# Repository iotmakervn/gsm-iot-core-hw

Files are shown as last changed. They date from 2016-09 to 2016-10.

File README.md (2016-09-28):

# Dự án GSM-IOT-CORE

## Mô tả tính năng

## Phần cứng

### Mạch nguyên lý

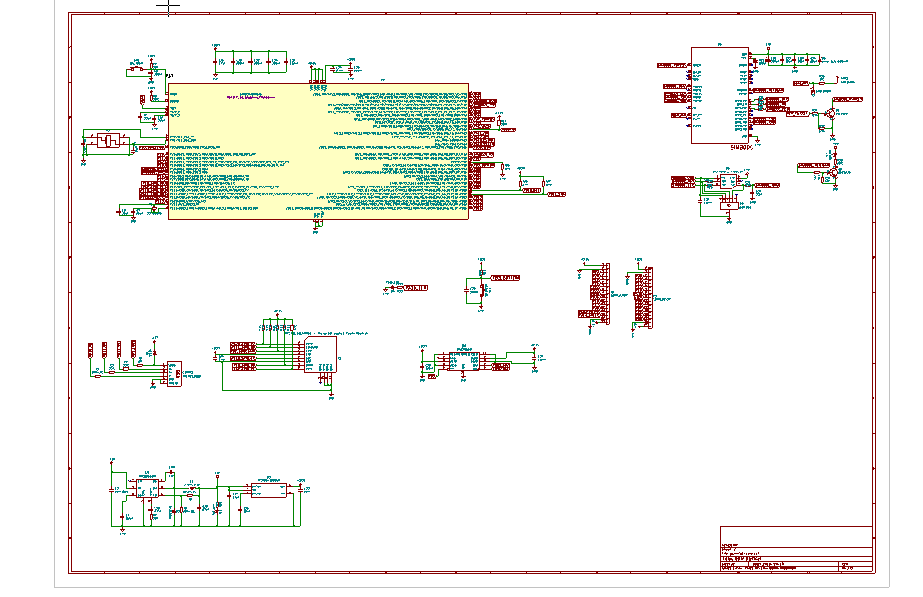
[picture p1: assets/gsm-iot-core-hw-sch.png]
GSM IOT CORE HW Schematic


### Mạch PCB

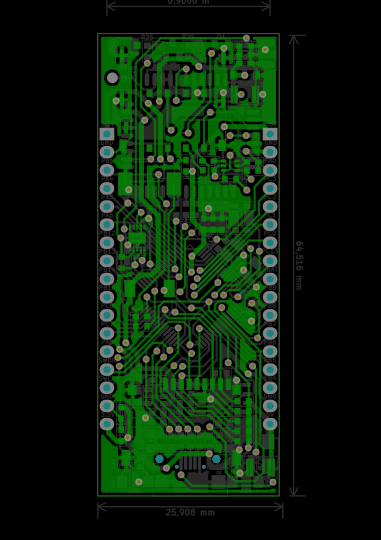
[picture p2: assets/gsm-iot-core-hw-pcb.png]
GSM IOT CORE HW PCB


### 3D
#### Top view
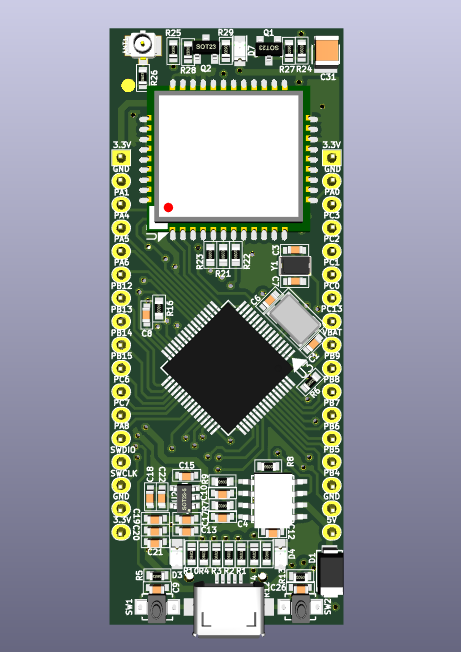
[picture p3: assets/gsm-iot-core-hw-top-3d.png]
GSM IOT CORE HW 3D TOP PCB


#### Button view
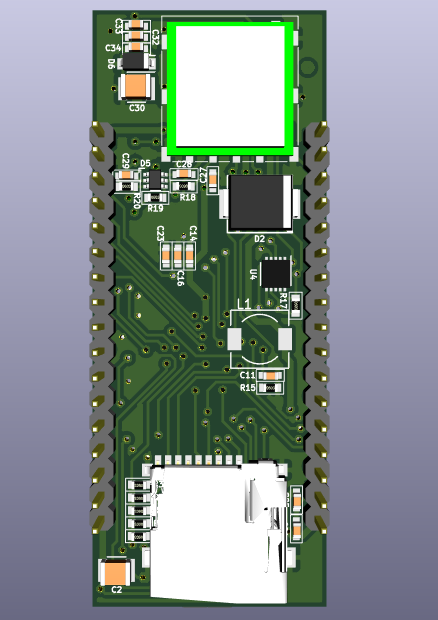
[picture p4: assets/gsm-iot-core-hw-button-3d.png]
GSM IOT CORE HW 3D TOP PCB


### Film

# Giấy phép

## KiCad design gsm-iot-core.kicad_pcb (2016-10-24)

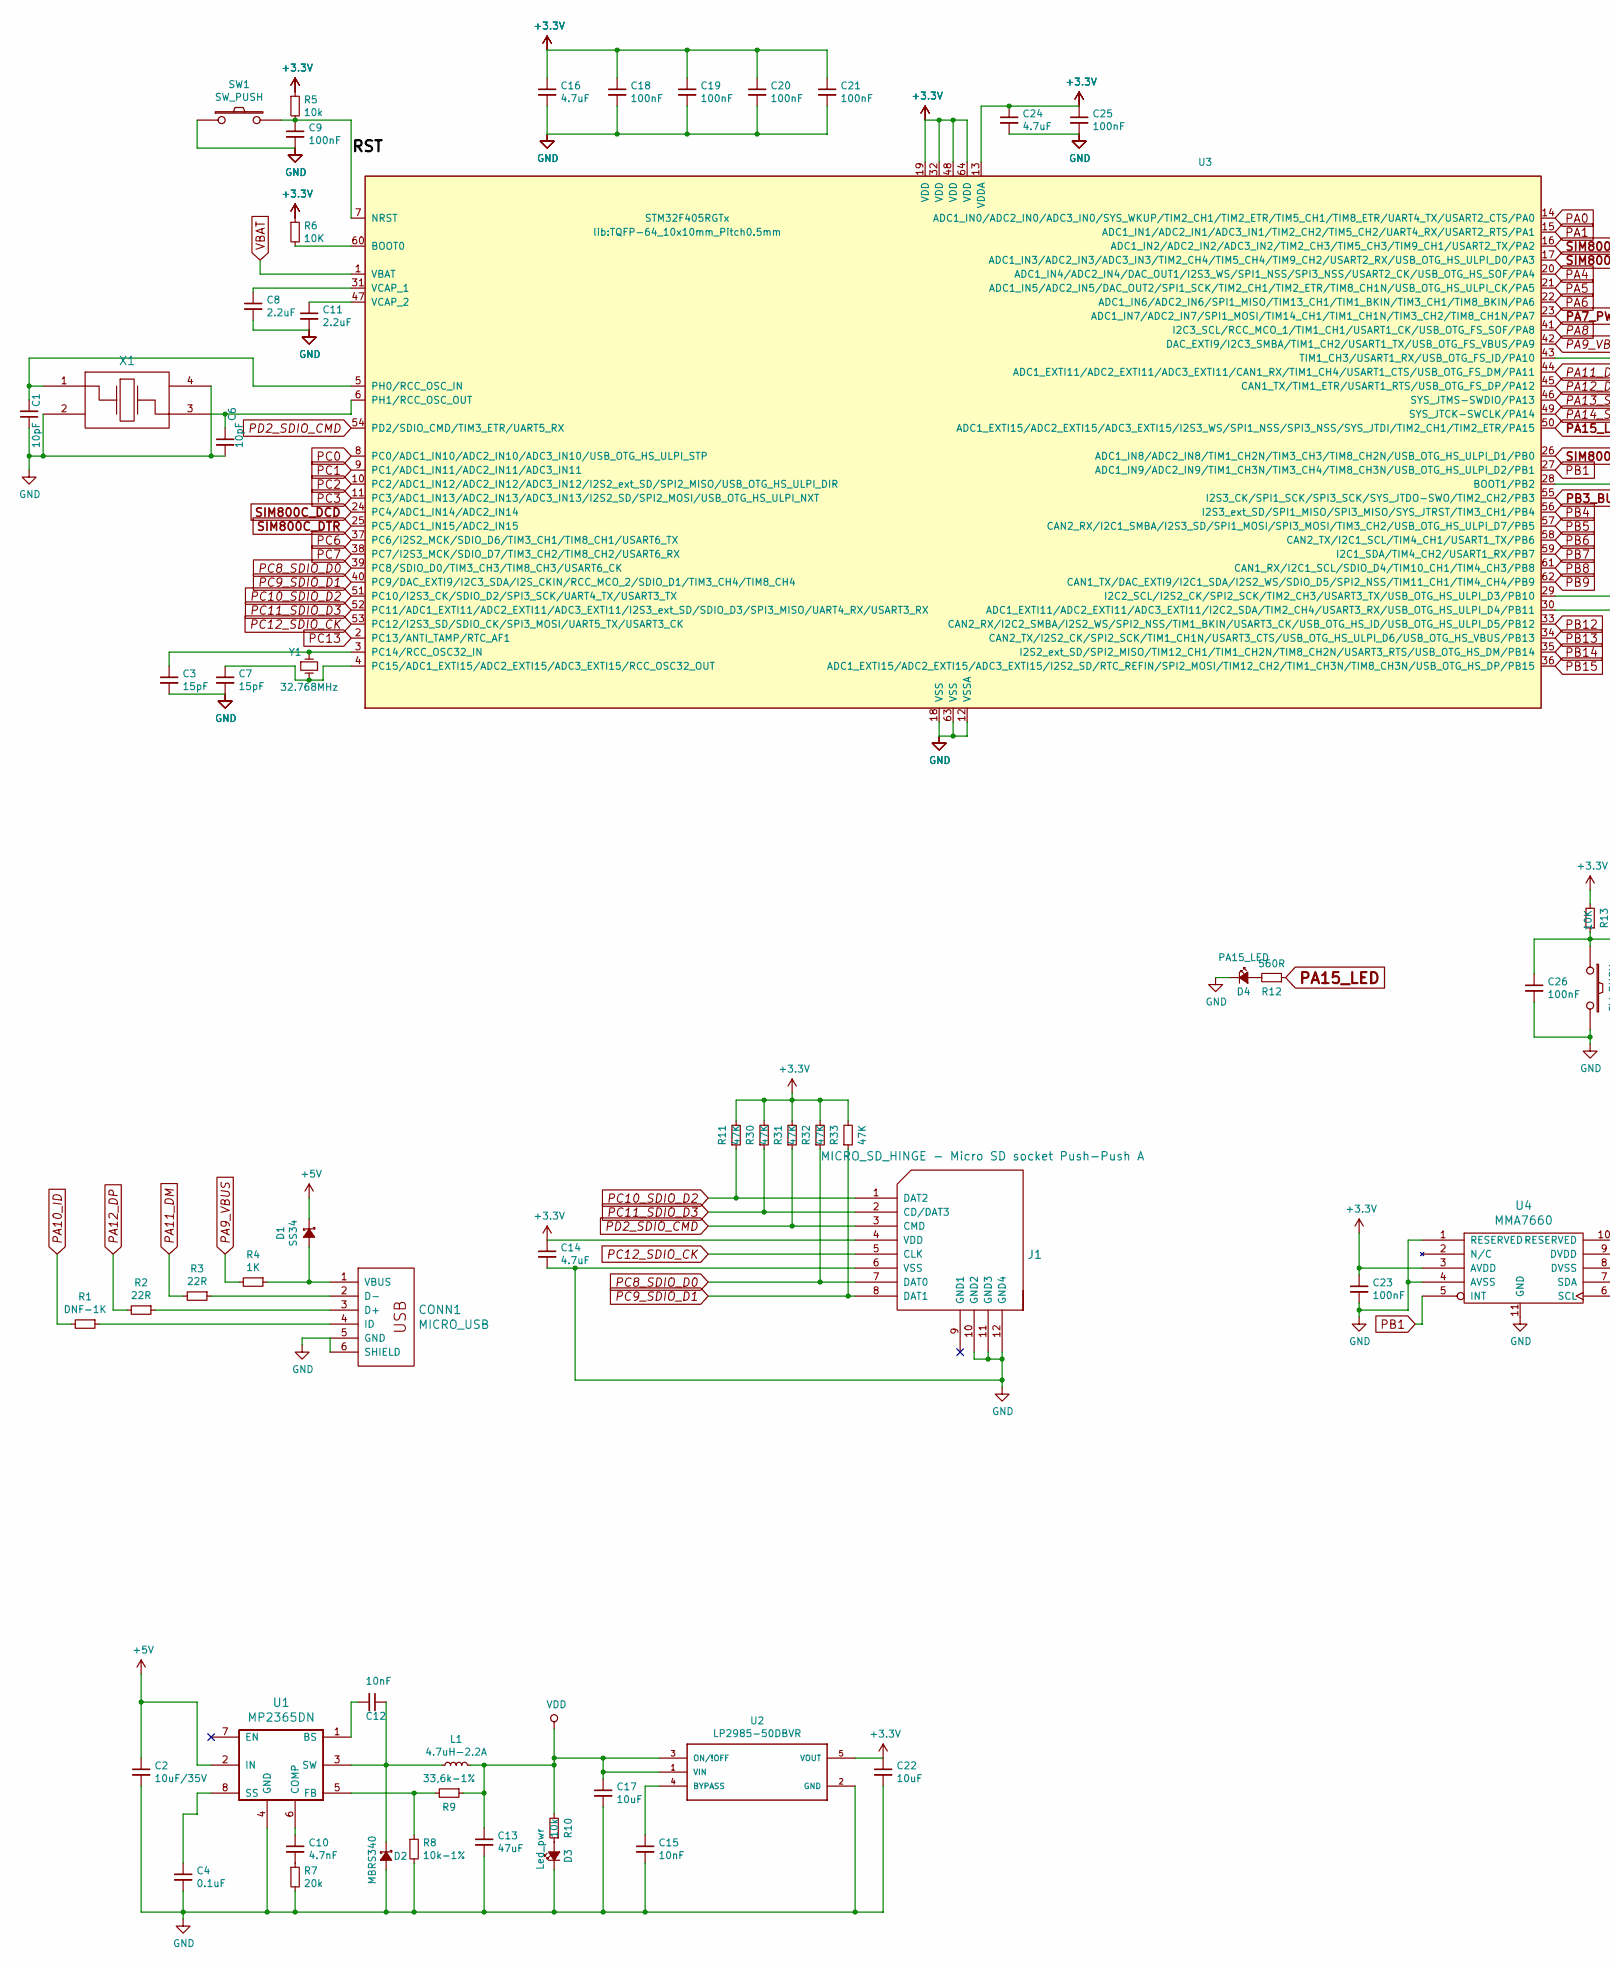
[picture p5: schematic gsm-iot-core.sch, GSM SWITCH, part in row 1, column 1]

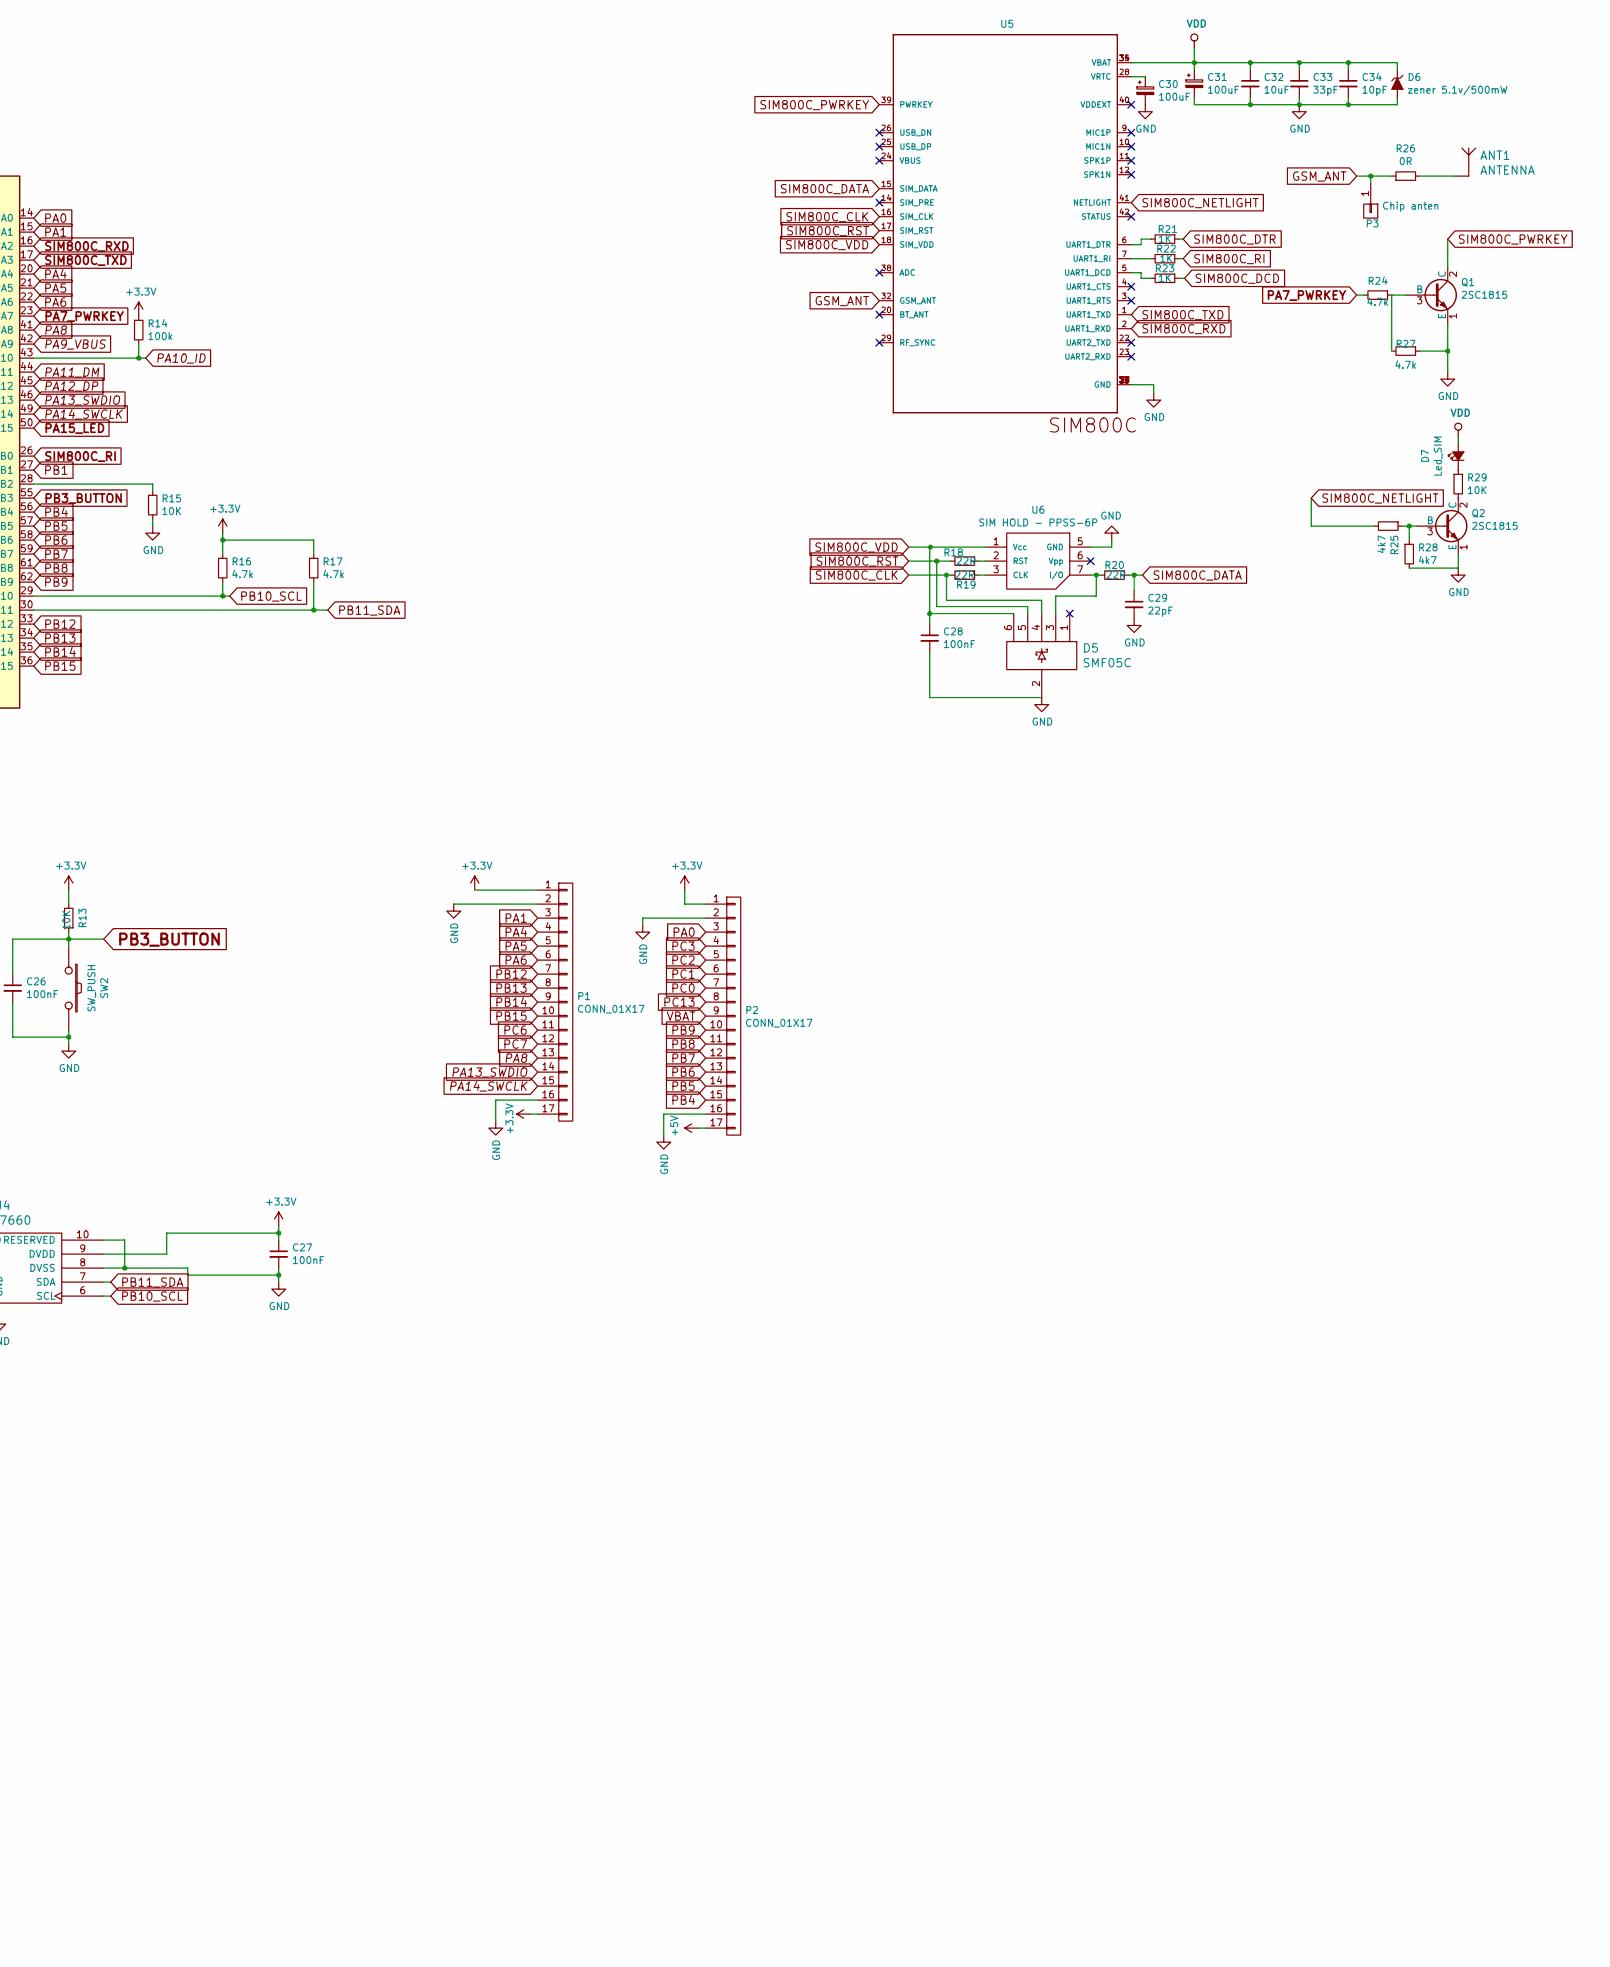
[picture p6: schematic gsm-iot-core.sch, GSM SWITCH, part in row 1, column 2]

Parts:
ANT1: ANTENNA; coaxial_u.fl-r-smt-1
C1, C6, C34: 10pF; C_0603
C2: 10uF/35V; C_1210
C3, C7: 15pF; C_0603
C4: 0.1uF; C_0603
C8, C11: 2.2uF; C_0603
C9, C18, C19, C20, C21, C23, C25, C26, C27, C28: 100nF; C_0603
C10: 4.7nF; C_0603
C12, C15: 10nF; C_0603
C13: 47uF; C_0603
C14, C16, C24: 4.7uF; C_0603
C17, C22, C32: 10uF; C_0603
C29: 22pF; C_0603
C30, C31: 100uF; C_1210
C33: 33pF; C_0603
CONN1: MICRO_USB; Micro_usb_B_smd
D1: SS34; do214ac
D2: MBRS340; do214ab
D3: Led_pwr; LED_0805
D4: PA15_LED; LED_0805
D5: SMF05C; SC-70-6
D6: zener 5.1v/500mW; SOD-123
D7: Led_SIM; LED_0805
J1: MICRO_SD_HINGE - Micro SD socket Push-Push A; MicroSD_Push-Push-A
L1: 4.7uH-2.2A; Choke_SMD_6.3x6.3_H3
P1, P2: CONN_01X17; Pin_Header_Straight_1x17
P3: Chip anten; point_test
Q1, Q2: 2SC1815; SOT-23
R1: DNF-1K; R_0603
R2, R3, R18, R19, R20: 22R; R_0603
R4, R21, R22, R23: 1K; R_0603
R5, R10: 10k; R_0603
R6, R13, R15, R29: 10K; R_0603
R7: 20k; R_0603
R8: 10k-1%; R_0603
R9: 33,6k-1%; R_0603
R11, R30, R31, R32, R33: 47K; R_0603
R12: 560R; R_0603
R14: 100k; R_0603
R16, R17, R24, R27: 4.7k; R_0603
R25, R28: 4k7; R_0603
R26: 0R; R_0603
SW1, SW2: SW_PUSH; SW_SPST_B3U-1000P-B
U1: MP2365DN; SOIC-8-N
U2: LP2985-50DBVR; SOT-23-5
U3: STM32F405RGTx; TQFP-64_10x10mm_Pitch0.5mm
U4: MMA7660; DFN-10-1EP_3x3mm_Pitch0.5mm
U5: SIM800C
U6: SIM HOLD - PPSS-6P; 115I-AEAA
X1: CRYSTAL-24M; Crystal_SMD_5032_4Pads
Y1: 32.768MHz; crystal_smd_32.768_2Pin

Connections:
+3V3: C14.1, C16.1, C18.1, C19.1, C20.1, C21.1, C22.1, C23.1, C24.1, C25.1, C27.1, J1.4 (VDD), P1.1, P1.17, P2.1, R5.1, R6.1, R11.2, R13.2, R14.1, R16.1, R17.1, R30.2, R31.2, R32.2, R33.2, U2.5 (VOUT), U3.13 (VDDA), U3.19 (VDD), U3.32 (VDD), U3.48 (VDD), U3.64 (VDD), U4.3 (AVDD), U4.9 (DVDD)
+5V: C2.1, D1.1 (K), P2.17, U1.2 (IN)
/RST: C9.1, R5.2, SW1.2, U3.7 (NRST)
GND: C1.1, C2.2, C3.2, C4.2, C6.2, C7.2, C8.2, C9.2, C11.2, C13.2, C14.2, C15.2, C16.2, C17.2, C18.2, C19.2, C20.2, C21.2, C22.2, C23.2, C24.2, C25.2, C26.2, C27.2, C28.2, C29.2, C30.2, C31.2, C32.2, C33.2, C34.2, CONN1.5 (GND), CONN1.6 (SHIELD), D2.2 (A), D3.1 (K), D4.1 (K), D5.2, D6.2 (A), J1.6 (VSS), J1.10 (GND2), J1.11 (GND3), J1.12 (GND4), P1.2, P1.16, P2.2, P2.16, Q1.1 (E), Q2.1 (E), R7.2, R8.2, R15.2, R27.1, R28.2, SW1.1, SW2.2, U1.4 (GND), U2.2 (GND), U3.12 (VSSA), U3.18 (VSS), U3.63 (VSS), U4.1 (RESERVED), U4.4 (AVSS), U4.8 (DVSS), U4.10 (RESERVED), U4.11 (GND), U5.8 (GND), U5.13 (GND), U5.19 (GND), U5.21 (GND), U5.27 (GND), U5.30 (GND), U5.31 (GND), U5.33 (GND), U5.36 (GND), U5.37 (GND), U6.5 (GND), X1.2, X1.4
GSM_ANT: P3.1, R26.1, U5.32 (GSM_ANT)
unnamed: ANT1.1, R26.2
unnamed: C1.2, U3.5 (PH0/RCC_OSC_IN), X1.1
unnamed: C3.1, U3.3 (PC14/RCC_OSC32_IN), Y1.1
unnamed: C4.1, U1.8 (SS)
unnamed: C6.1, U3.6 (PH1/RCC_OSC_OUT), X1.3
unnamed: C7.1, U3.4 (PC15/ADC1_EXTI15/ADC2_EXTI15/ADC3_EXTI1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), Y1.2
unnamed: C8.1, U3.31 (VCAP_1)
unnamed: C10.1, U1.6 (COMP)
unnamed: C10.2, R7.1
unnamed: C11.1, U3.47 (VCAP_2)
unnamed: C12.1, D2.1 (K), L1.1, U1.3 (SW)
unnamed: C12.2, U1.1 (BS)
unnamed: C15.1, U2.4 (BYPASS)
unnamed: C28.1, D5.6
unnamed: C30.1, U5.28 (VRTC)
unnamed: CONN1.1 (VBUS), D1.2 (A), R4.1
unnamed: CONN1.2 (D-), R3.1
unnamed: CONN1.3 (D+), R2.1
unnamed: CONN1.4 (ID), R1.1
unnamed: D3.2 (A), R10.1
unnamed: D4.2 (A), R12.2
unnamed: D5.3, R20.2, U6.7 (I/O)
unnamed: D7.1 (K), R29.1
unnamed: Q1.3 (B), R24.1, R27.2
unnamed: Q2.2 (C), R29.2
unnamed: Q2.3 (B), R25.1, R28.1
unnamed: R6.2, U3.60 (BOOT0)
unnamed: R8.1, R9.2, U1.5 (FB)
unnamed: R15.1, U3.28 (BOOT1/PB2)
unnamed: R18.1, U6.2 (RST)
unnamed: R19.1, U6.3 (CLK)
unnamed: R21.2, U5.6 (UART1_DTR)
unnamed: R22.2, U5.7 (UART1_RI)
unnamed: R23.2, U5.5 (UART1_DCD)
PA0: P2.3, U3.14 (ADC1_IN0/ADC2_IN0/ADC3_IN0/SYS_WKUP/TIM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)
PA1: P1.3, U3.15 (ADC1_IN1/ADC2_IN1/ADC3_IN1/TIM2_CH2/TIM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)
PA4: P1.4, U3.20 (ADC1_IN4/ADC2_IN4/DAC_OUT1/I2S3_WS/SPI1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)
PA5: P1.5, U3.21 (ADC1_IN5/ADC2_IN5/DAC_OUT2/SPI1_SCK/TIM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)
PA6: P1.6, U3.22 (ADC1_IN6/ADC2_IN6/SPI1_MISO/TIM13_CH1/T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)
PA7_PWRKEY: R24.2, U3.23 (ADC1_IN7/ADC2_IN7/SPI1_MOSI/TIM14_CH1/T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)
PA8: P1.13, U3.41 (I2C3_SCL/RCC_MCO_1/TIM1_CH1/USART1_CK/U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)
PA9_VBUS: R4.2, U3.42 (DAC_EXTI9/I2C3_SMBA/TIM1_CH2/USART1_TX/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)
PA10_ID: R1.2, R14.2, U3.43 (TIM1_CH3/USART1_RX/USB_OTG_FS_ID/PA10)
PA11_DM: R3.2, U3.44 (ADC1_EXTI11/ADC2_EXTI11/ADC3_EXTI11/CAN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)
PA12_DP: R2.2, U3.45 (CAN1_TX/TIM1_ETR/USART1_RTS/USB_OTG_FS_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)
PA13_SWDIO: P1.14, U3.46 (SYS_JTMS-SWDIO/PA13)
PA14_SWCLK: P1.15, U3.49 (SYS_JTCK-SWCLK/PA14)
PA15_LED: R12.1, U3.50 (ADC1_EXTI15/ADC2_EXTI15/ADC3_EXTI15/I2S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)
PB1: U3.27 (ADC1_IN9/ADC2_IN9/TIM1_CH3N/TIM3_CH4/TI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), U4.5 (INT)
PB3_BUTTON: C26.1, R13.1, SW2.1, U3.55 (I2S3_CK/SPI1_SCK/SPI3_SCK/SYS_JTDO-SWO/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)
PB4: P2.15, U3.56 (I2S3_ext_SD/SPI1_MISO/SPI3_MISO/SYS_JTR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)
PB5: P2.14, U3.57 (CAN2_RX/I2C1_SMBA/I2S3_SD/SPI1_MOSI/SPI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)
PB6: P2.13, U3.58 (CAN2_TX/I2C1_SCL/TIM4_CH1/USART1_TX/PB6)
PB7: P2.12, U3.59 (I2C1_SDA/TIM4_CH2/USART1_RX/PB7)
PB8: P2.11, U3.61 (CAN1_RX/I2C1_SCL/SDIO_D4/TIM10_CH1/TIM4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)
PB9: P2.10, U3.62 (CAN1_TX/DAC_EXTI9/I2C1_SDA/I2S2_WS/SDIO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)
PB10_SCL: R16.2, U3.29 (I2C2_SCL/I2S2_CK/SPI2_SCK/TIM2_CH3/USAR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), U4.6 (SCL)
PB11_SDA: R17.2, U3.30 (ADC1_EXTI11/ADC2_EXTI11/ADC3_EXTI11/I2C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), U4.7 (SDA)
PB12: P1.7, U3.33 (CAN2_RX/I2C2_SMBA/I2S2_WS/SPI2_NSS/TIM1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)
PB13: P1.8, U3.34 (CAN2_TX/I2S2_CK/SPI2_SCK/TIM1_CH1N/USAR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)
PB14: P1.9, U3.35 (I2S2_ext_SD/SPI2_MISO/TIM12_CH1/TIM1_CH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)
PB15: P1.10, U3.36 (ADC1_EXTI15/ADC2_EXTI15/ADC3_EXTI15/I2S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)
PC0: P2.7, U3.8 (PC0/ADC1_IN10/ADC2_IN10/ADC3_IN10/USB_O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)
PC1: P2.6, U3.9 (PC1/ADC1_IN11/ADC2_IN11/ADC3_IN11)
PC2: P2.5, U3.10 (PC2/ADC1_IN12/ADC2_IN12/ADC3_IN12/I2S2_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)
PC3: P2.4, U3.11 (PC3/ADC1_IN13/ADC2_IN13/ADC3_IN13/I2S2_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)
PC6: P1.11, U3.37 (PC6/I2S2_MCK/SDIO_D6/TIM3_CH1/TIM8_CH1/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)
PC7: P1.12, U3.38 (PC7/I2S3_MCK/SDIO_D7/TIM3_CH2/TIM8_CH2/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)
PC8_SDIO_D0: J1.7 (DAT0), R32.1, U3.39 (PC8/SDIO_D0/TIM3_CH3/TIM8_CH3/USART6_CK)
PC9_SDIO_D1: J1.8 (DAT1), R33.1, U3.40 (PC9/DAC_EXTI9/I2C3_SDA/I2S_CKIN/RCC_MCO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)
PC10_SDIO_D2: J1.1 (DAT2), R11.1, U3.51 (PC10/I2S3_CK/SDIO_D2/SPI3_SCK/UART4_TX/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)
PC11_SDIO_D3: J1.2 (CD/DAT3), R30.1, U3.52 (PC11/ADC1_EXTI11/ADC2_EXTI11/ADC3_EXTI1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)
PC12_SDIO_CK: J1.5 (CLK), U3.53 (PC12/I2S3_SD/SDIO_CK/SPI3_MOSI/UART5_TX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)
PC13: P2.8, U3.2 (PC13/ANTI_TAMP/RTC_AF1)
PD2_SDIO_CMD: J1.3 (CMD), R31.1, U3.54 (PD2/SDIO_CMD/TIM3_ETR/UART5_RX)
SIM800C_CLK: D5.4, R19.2, U5.16 (SIM_CLK)
SIM800C_DATA: C29.1, R20.1, U5.15 (SIM_DATA)
SIM800C_DCD: R23.1, U3.24 (PC4/ADC1_IN14/ADC2_IN14)
SIM800C_DTR: R21.1, U3.25 (PC5/ADC1_IN15/ADC2_IN15)
SIM800C_NETLIGHT: R25.2, U5.41 (NETLIGHT)
SIM800C_PWRKEY: Q1.2 (C), U5.39 (PWRKEY)
SIM800C_RI: R22.1, U3.26 (ADC1_IN8/ADC2_IN8/TIM1_CH2N/TIM3_CH3/TI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)
SIM800C_RST: D5.5, R18.2, U5.17 (SIM_RST)
SIM800C_RXD: U3.16 (ADC1_IN2/ADC2_IN2/ADC3_IN2/TIM2_CH3/TIM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), U5.2 (UART1_RXD)
SIM800C_TXD: U3.17 (ADC1_IN3/ADC2_IN3/ADC3_IN3/TIM2_CH4/TIM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), U5.1 (UART1_TXD)
SIM800C_VDD: U5.18 (SIM_VDD), U6.1 (Vcc)
VBAT: P2.9, U3.1 (VBAT)
VDD: C13.1, C17.1, C31.1, C32.1, C33.1, C34.1, D6.1 (K), D7.2 (A), L1.2, R9.1, R10.2, U2.1 (VIN), U2.3 (ON/!OFF), U5.34 (VBAT), U5.35 (VBAT)

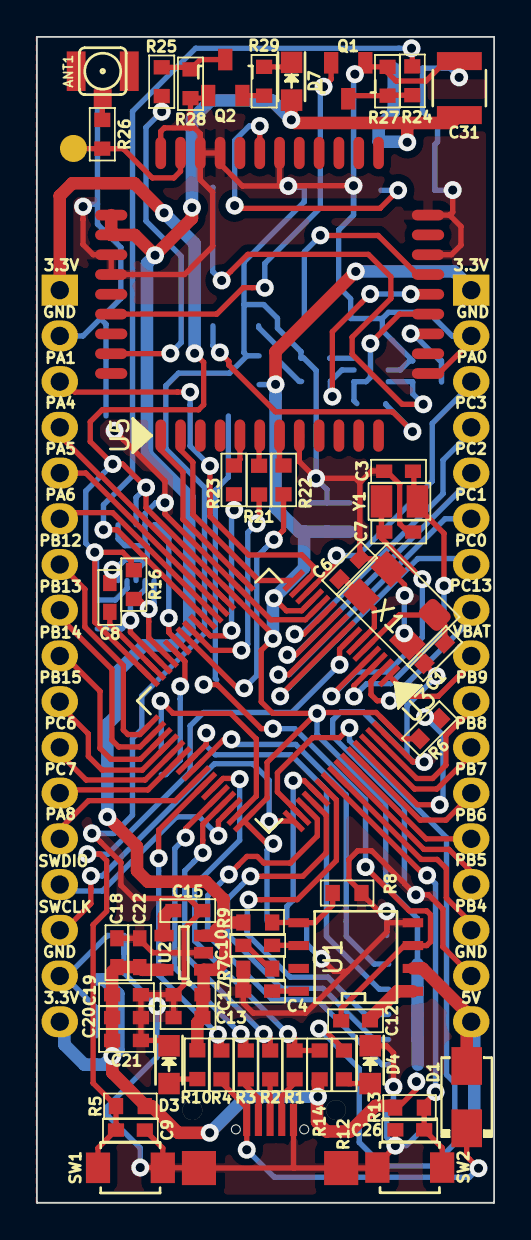
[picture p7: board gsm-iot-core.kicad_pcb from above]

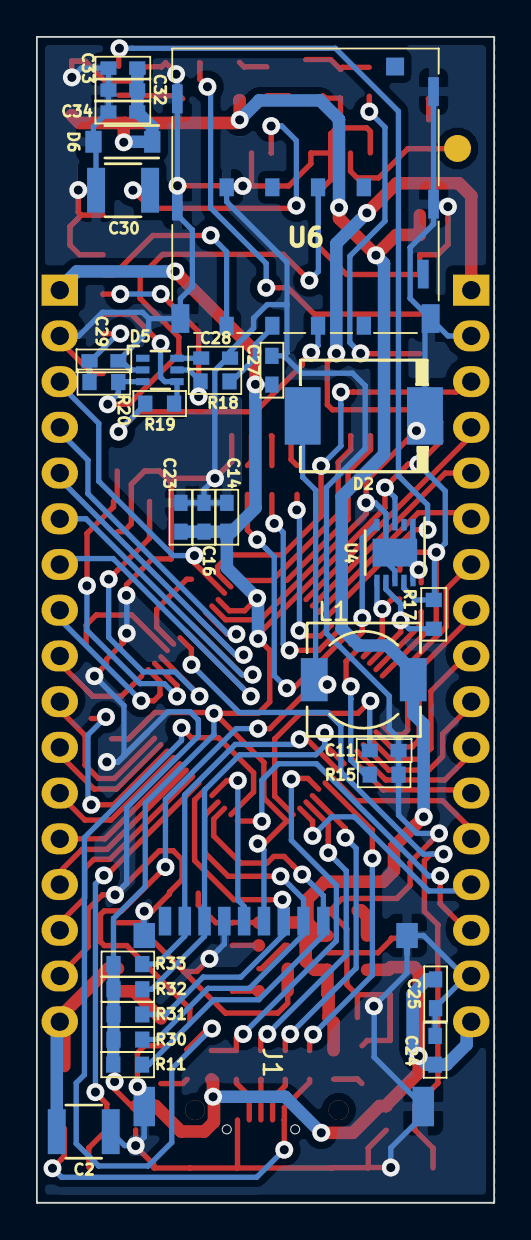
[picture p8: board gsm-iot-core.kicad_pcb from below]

Board: 2 copper layers, 25.4 x 64.8 mm, 92 parts (31 on the bottom side), 93 nets.

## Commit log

2016-08-12 Create project, but need to check connect between STM32 & SIM800C
    [gsm-iot-core.sch]
2016-09-06 add .gitignore
    [gsm-iot-core.sch]
2016-09-15 branch upstream
    [gsm-iot-core.csv, gsm-iot-core.sch, gsm-iot-core.xlsx]
2016-09-15 Error add footprint-not updata footprint, local of component is bad
    [gsm-iot-core.kicad_pcb, gsm-iot-core.sch]
2016-09-15 add assets file and fix README
    [gsm-iot-core.kicad_pcb]
2016-09-15 Fix error invalid foortprint- a error footprint file, add new footprint for component
    [gsm-iot-core.kicad_pcb, gsm-iot-core.sch]
2016-09-16 new PCB
    [gsm-iot-core.kicad_pcb, gsm-iot-core.sch]
2016-09-26 fix 3th
    [gsm-iot-core.kicad_pcb, gsm-iot-core.sch]
2016-09-28 PCB new
    [gsm-iot-core.kicad_pcb, gsm-iot-core.sch]
2016-09-29 Branch LONGER
    [gsm-iot-core.kicad_pcb, gsm-iot-core.sch]
2016-10-02 fix PCB
    [gsm-iot-core.kicad_pcb, gsm-iot-core.sch]
2016-10-06 Fix power part of schematic & footprint crystal
    [gsm-iot-core.kicad_pcb, gsm-iot-core.sch]
2016-10-07 Modify microSD diagram & connect betwenn MMA7660 and STM
    [gsm-iot-core.kicad_pcb, gsm-iot-core.sch]
2016-10-07 Modify length board 9x2,7 (in)
    [gsm-iot-core.kicad_pcb]
2016-10-08 setup component
    [gsm-iot-core.kicad_pcb]
2016-10-11 all connect usb & SD card well
    [gsm-iot-core.kicad_pcb]
2016-10-20 completed connect tracks
    [gsm-iot-core.kicad_pcb, gsm-iot-core.sch]
2016-10-23 fix 1/3 via & track distance
    [gsm-iot-core.kicad_pcb]
2016-10-24 Final pcb
    [gsm-iot-core.kicad_pcb]
